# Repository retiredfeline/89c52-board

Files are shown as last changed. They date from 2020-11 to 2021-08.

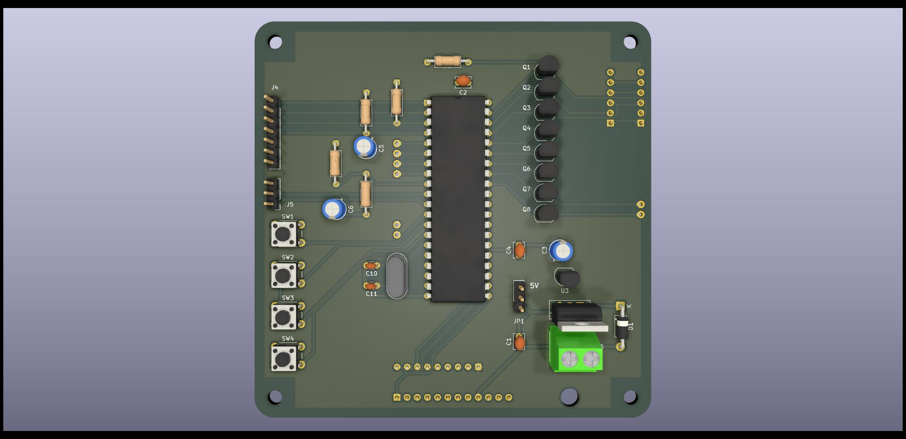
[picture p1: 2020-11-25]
89c52board-front-raytraced.jpg

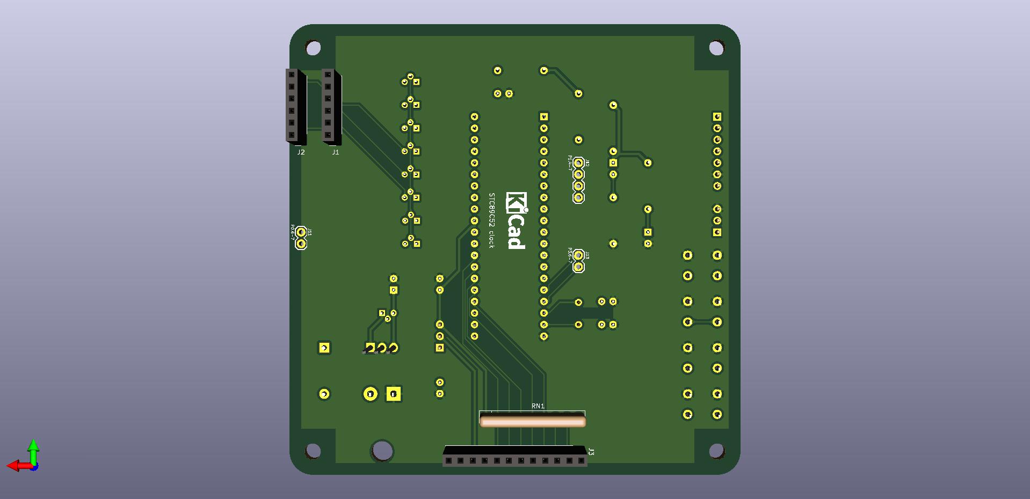
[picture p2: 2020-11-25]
89c52board-back.jpg

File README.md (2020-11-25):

# 89c52 clock board

These are the design files for the 89C52 clock PCB described in [this Hackaday project](https://hackaday.io/project/175986-89c52-clock-board). It plugs onto the back of the [6 segment](https://hackaday.io/project/175397-6-segment-2-digit-led-display-board) and [7 segment](https://hackaday.io/project/175432-7-segment-2-digit-led-display-board) cascadable boards. The firmware is published at [89C52 clock](https://github.com/kenyapcomau/89c52-clock).

## Versioning

First release December 2020

## Notes

Not all the component locations on the board need to be populated, see the notes in the schematic.

## Authors

* **Ken Yap**

## License

See the [LICENSE](LICENSE.md) file for license rights and limitations (MIT).

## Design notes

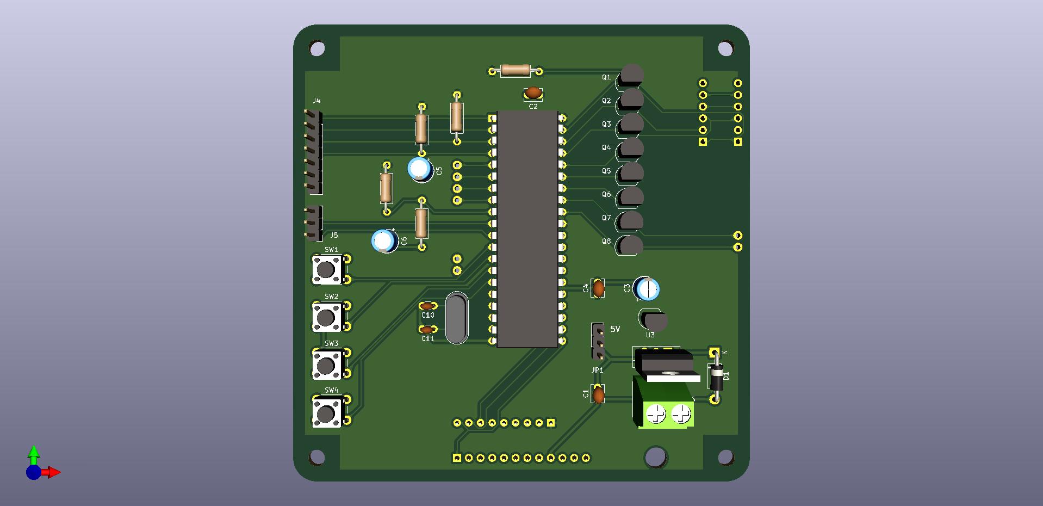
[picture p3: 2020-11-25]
89c52board-front.jpg

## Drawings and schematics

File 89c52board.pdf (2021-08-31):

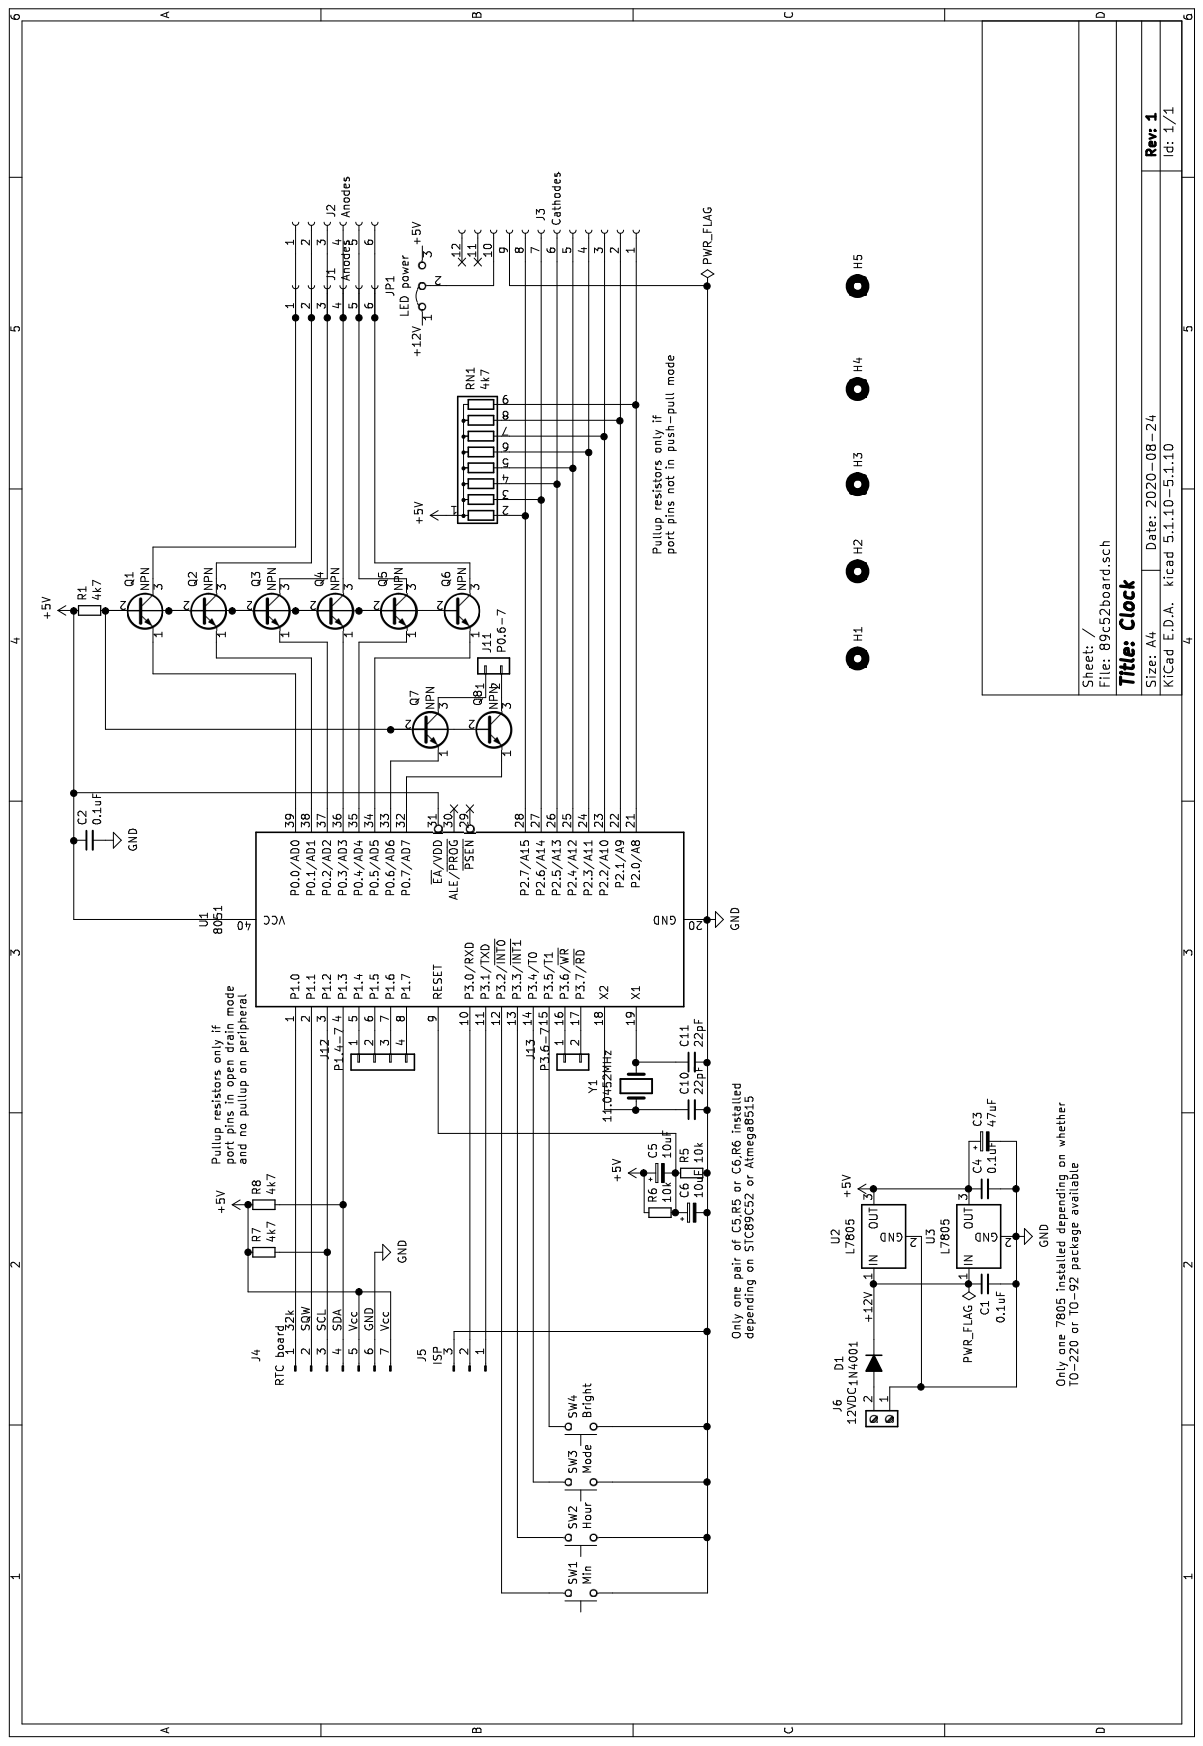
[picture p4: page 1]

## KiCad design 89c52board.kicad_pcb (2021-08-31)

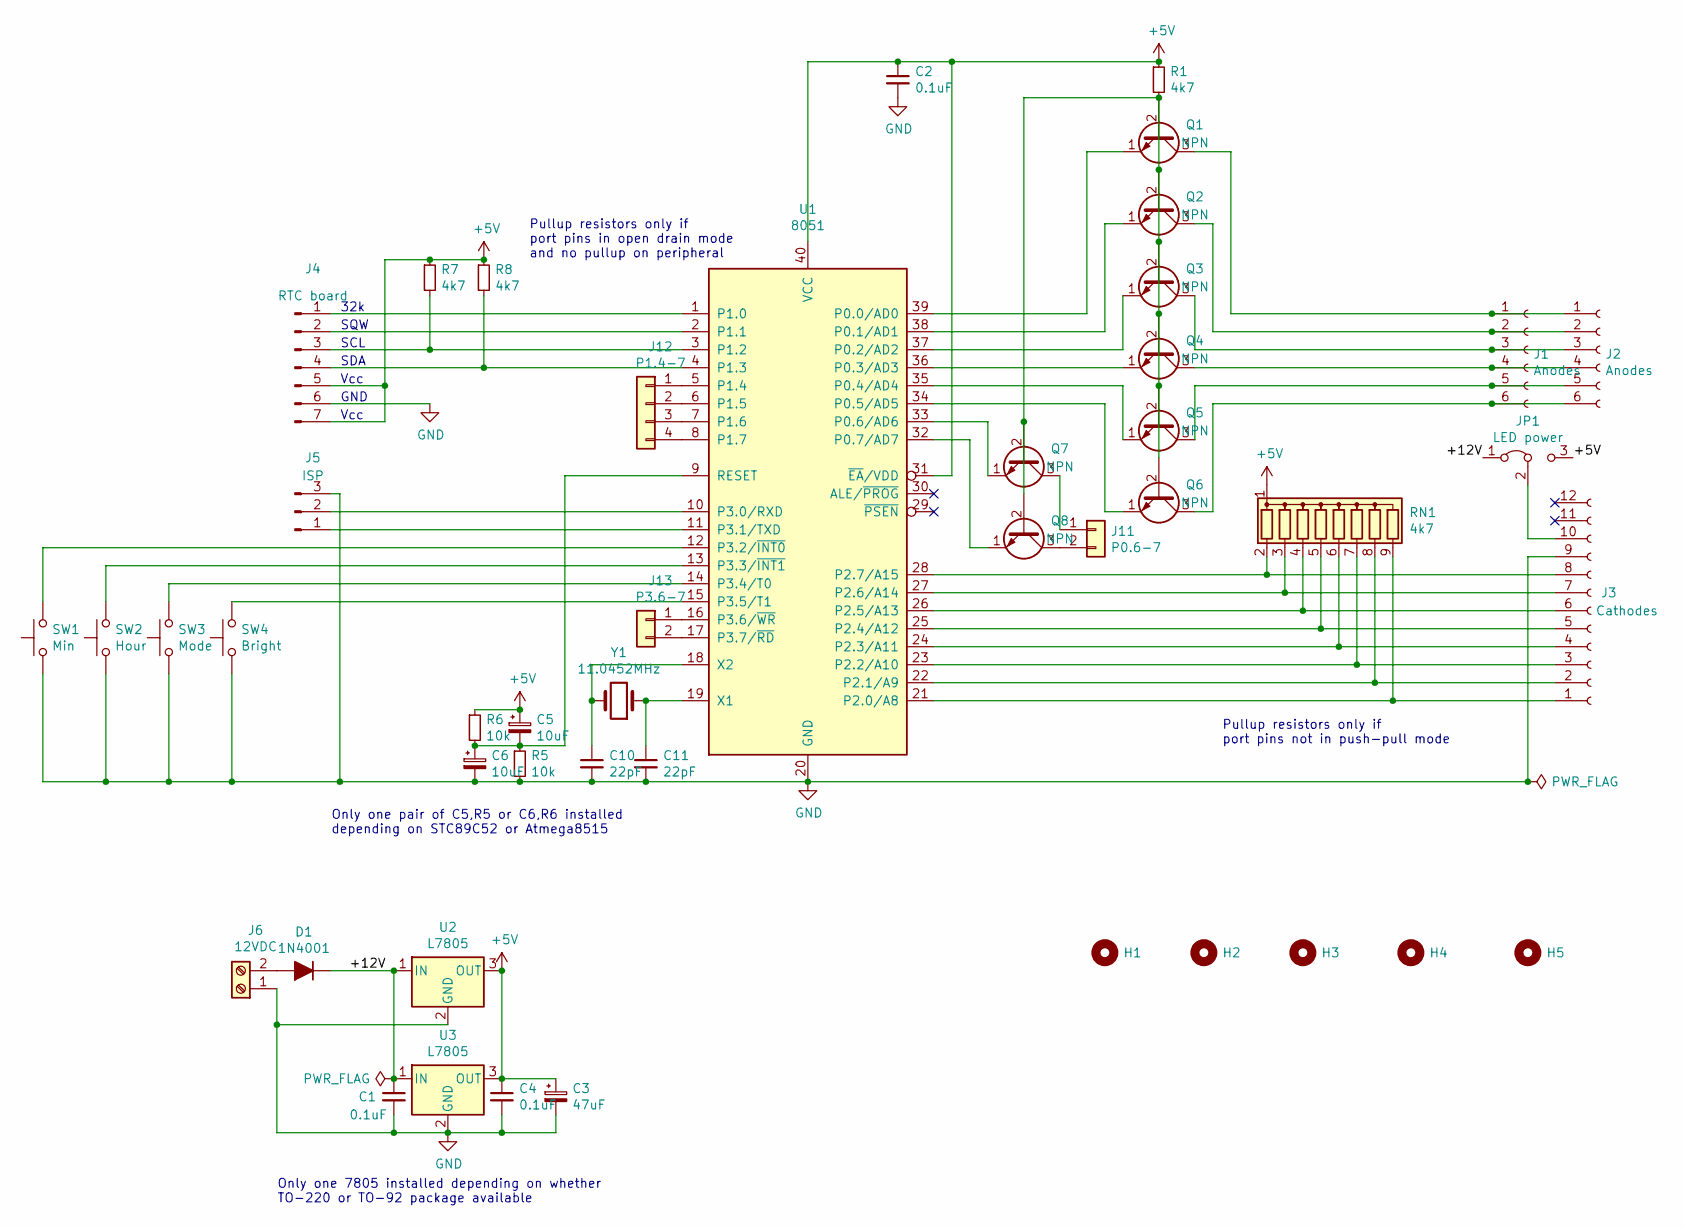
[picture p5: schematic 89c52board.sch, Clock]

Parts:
C1, C2, C4: 0.1uF; C_Disc_D3.8mm_W2.6mm_P2.50mm
C3: 47uF; CP_Radial_D5.0mm_P2.50mm
C5, C6: 10uF; CP_Radial_D5.0mm_P2.50mm
C10, C11: 22pF; C_Disc_D3.0mm_W1.6mm_P2.50mm
D1: 1N4001; D_DO-41_SOD81_P10.16mm_Horizontal
H1, H2, H3, H4: MountingHole; MountingHole_3.5mm
H5: MountingHole; MountingHole_4.5mm
J1, J2: Anodes; PinSocket_1x06_P2.54mm_Vertical
J3: Cathodes; PinSocket_1x12_P2.54mm_Vertical
J4: RTC board; PinHeader_1x07_P2.54mm_Vertical
J5: ISP; PinHeader_1x03_P2.54mm_Vertical
J6: 12VDC; TerminalBlock_bornier-2_P5.08mm
J11: P0.6-7; 1X02
J12: P1.4-7; 1X04
J13: P3.6-7; 1X02
JP1: LED power; PinHeader_1x03_P2.54mm_Vertical
Q1, Q2, Q3, Q4, Q5, Q6, Q7, Q8: NPN; TO-92
R1, R7, R8: 4k7; R_Axial_DIN0207_L6.3mm_D2.5mm_P10.16mm_Horizontal
R5, R6: 10k; R_Axial_DIN0207_L6.3mm_D2.5mm_P10.16mm_Horizontal
RN1: 4k7; R_Array_SIP9
SW1: Min; SW_PUSH_6mm_H5mm
SW2: Hour; SW_PUSH_6mm_H5mm
SW3: Mode; SW_PUSH_6mm_H5mm
SW4: Bright; SW_PUSH_6mm_H5mm
U1: 8051; DIP-40_W15.24mm
U2: L7805; TO-220-3_Vertical
U3: L7805; TO-92
Y1: 11.0452MHz; Crystal_HC49-4H_Vertical

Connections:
+5V: C2.1, C3.1, C4.1, C5.1, J4.5, J4.7, JP1.3 (B), R1.1, R6.1, R7.1, R8.1, RN1.1 (common), U1.31 (~EA~/VDD), U1.40 (VCC), U2.3 (OUT), U3.3 (OUT)
/+12V: C1.1, D1.1 (K), JP1.1 (A), U2.1 (IN), U3.1 (IN)
GND: C1.2, C2.2, C3.2, C4.2, C6.2, C10.2, C11.2, J3.9, J4.6, J5.3, J6.1, R5.2, SW1.1, SW2.1, SW3.1, SW4.1, U1.20 (GND), U2.2 (GND), U3.2 (GND)
unnamed: C5.2, C6.1, R5.1, R6.2, U1.9 (RESET)
unnamed: C10.1, U1.18 (X2), Y1.2
unnamed: C11.1, U1.19 (X1), Y1.1
unnamed: D1.2 (A), J6.2
unnamed: J1.1, J2.1, Q1.3 (C)
unnamed: J1.2, J2.2, Q2.3 (C)
unnamed: J1.3, J2.3, Q3.3 (C)
unnamed: J1.4, J2.4, Q4.3 (C)
unnamed: J1.5, J2.5, Q5.3 (C)
unnamed: J1.6, J2.6, Q6.3 (C)
unnamed: J3.1, RN1.9 (R8), U1.21 (P2.0/A8)
unnamed: J3.2, RN1.8 (R7), U1.22 (P2.1/A9)
unnamed: J3.3, RN1.7 (R6), U1.23 (P2.2/A10)
unnamed: J3.4, RN1.6 (R5), U1.24 (P2.3/A11)
unnamed: J3.5, RN1.5 (R4), U1.25 (P2.4/A12)
unnamed: J3.6, RN1.4 (R3), U1.26 (P2.5/A13)
unnamed: J3.7, RN1.3 (R2), U1.27 (P2.6/A14)
unnamed: J3.8, RN1.2 (R1), U1.28 (P2.7/A15)
unnamed: J3.10, JP1.2 (C)
unnamed: J4.1, U1.1 (P1.0)
unnamed: J4.2, U1.2 (P1.1)
unnamed: J4.3, R7.2, U1.3 (P1.2)
unnamed: J4.4, R8.2, U1.4 (P1.3)
unnamed: J5.1, U1.11 (P3.1/TXD)
unnamed: J5.2, U1.10 (P3.0/RXD)
unnamed: J11.1, Q7.3 (C)
unnamed: J11.2, Q8.3 (C)
unnamed: J12.1, U1.5 (P1.4)
unnamed: J12.2, U1.6 (P1.5)
unnamed: J12.3, U1.7 (P1.6)
unnamed: J12.4, U1.8 (P1.7)
unnamed: J13.1, U1.16 (P3.6/~WR~)
unnamed: J13.2, U1.17 (P3.7/~RD~)
unnamed: Q1.1 (E), U1.39 (P0.0/AD0)
unnamed: Q1.2 (B), Q2.2 (B), Q3.2 (B), Q4.2 (B), Q5.2 (B), Q6.2 (B), Q7.2 (B), Q8.2 (B), R1.2
unnamed: Q2.1 (E), U1.38 (P0.1/AD1)
unnamed: Q3.1 (E), U1.37 (P0.2/AD2)
unnamed: Q4.1 (E), U1.36 (P0.3/AD3)
unnamed: Q5.1 (E), U1.35 (P0.4/AD4)
unnamed: Q6.1 (E), U1.34 (P0.5/AD5)
unnamed: Q7.1 (E), U1.33 (P0.6/AD6)
unnamed: Q8.1 (E), U1.32 (P0.7/AD7)
unnamed: SW1.2, U1.12 (P3.2/~INT0~)
unnamed: SW2.2, U1.13 (P3.3/~INT1~)
unnamed: SW3.2, U1.14 (P3.4/T0)
unnamed: SW4.2, U1.15 (P3.5/T1)

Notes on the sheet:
Only one pair of C5,R5 or C6,R6 installed depending on STC89C52 or Atmega8515
Only one 7805 installed depending on whether TO-220 or TO-92 package available
SCL
SDA
Vcc
GND
32k
SQW
Pullup resistors only if port pins in open drain mode and no pullup on peripheral
Pullup resistors only if port pins not in push-pull mode

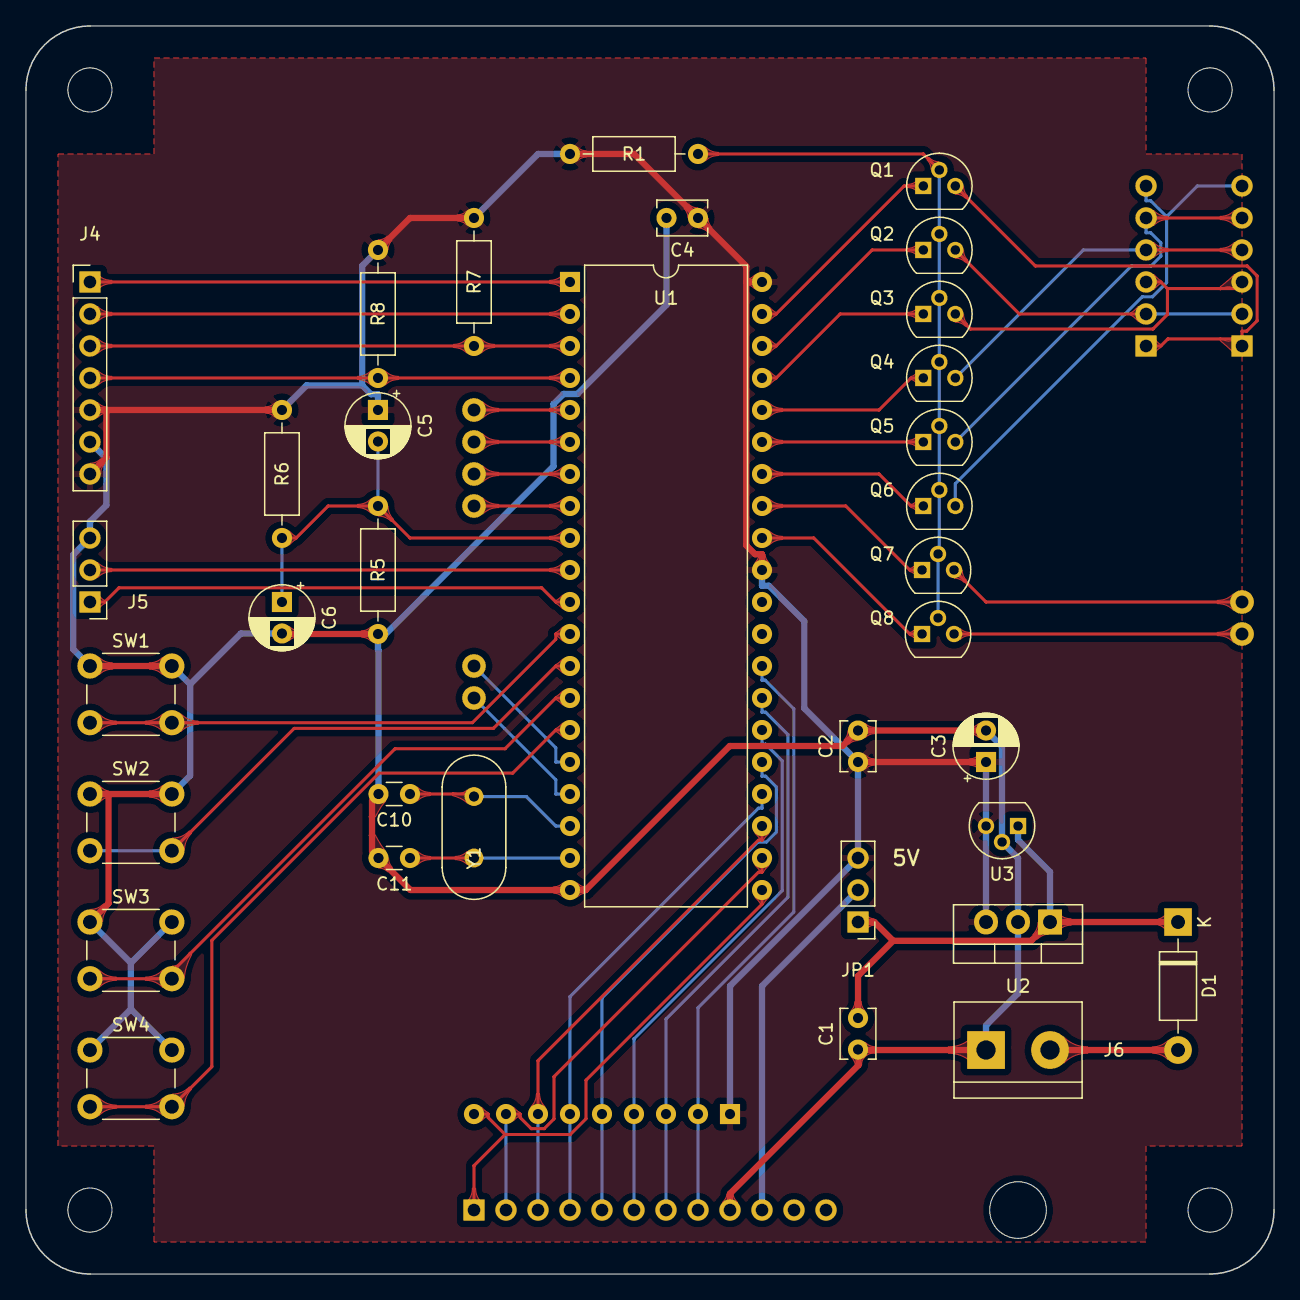
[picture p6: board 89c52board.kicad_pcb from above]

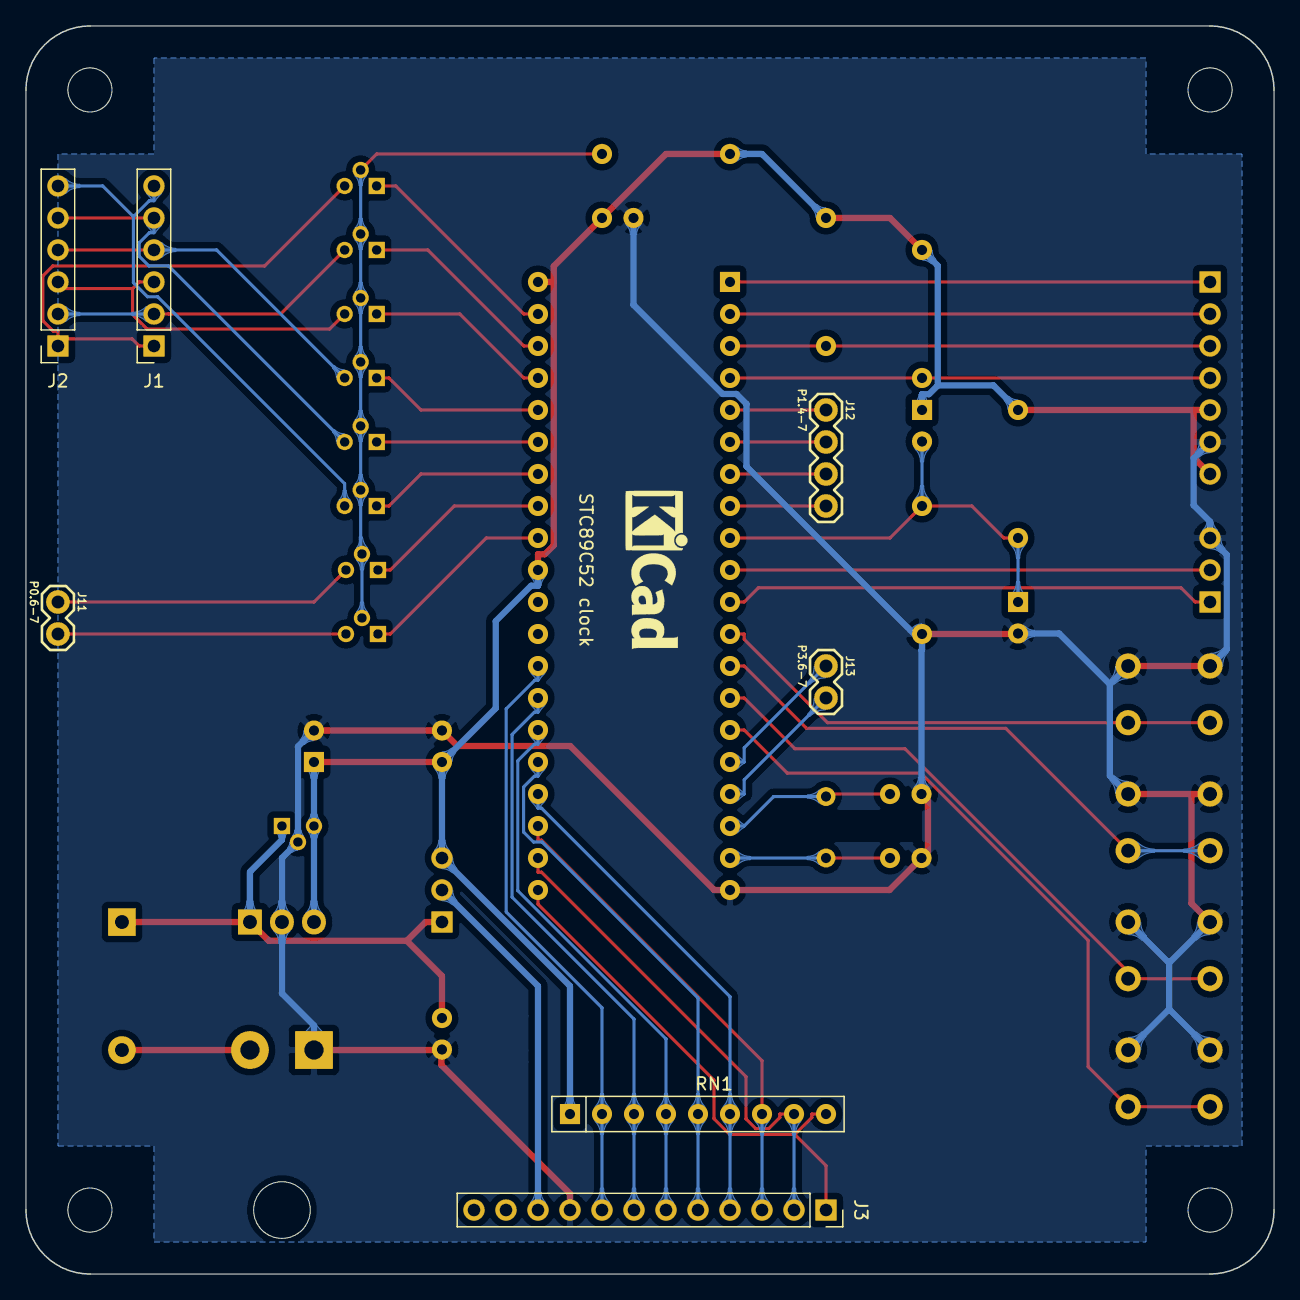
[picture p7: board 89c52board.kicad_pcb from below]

Board: 2 copper layers, 99.1 x 99.1 mm, 46 parts (7 on the bottom side), 49 nets.

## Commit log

2020-11-30 Cosmetic: swap C2 and C4 labels to better reflect their positions on board
    [89c52board.kicad_pcb, 89c52board.sch]
2021-08-31 More suitable values for I2C pullup resistors and digit driver transistor base resistor. Board unchanged
    [89c52board.kicad_pcb, 89c52board.sch]
